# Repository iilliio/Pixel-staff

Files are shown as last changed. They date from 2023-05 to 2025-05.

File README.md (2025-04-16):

<h1>
Open Pixel Poi
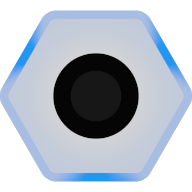
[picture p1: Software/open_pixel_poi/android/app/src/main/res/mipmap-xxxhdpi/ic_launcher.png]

</h1>

<h4>
  <a href="https://discord.gg/hErUF8A4">Store</a>
  ·
  <a href="./Firmware/MANUAL.md">User Guide</a>
  ·
  <a href="./Hardware/3D Printable Body/README.md">3D Models</a>
  ·
  <a href="./Hardware/Assembly/README.md">Assembly</a>
  ·
  <a href="./Software/README.md">Android App</a>
  ·
  <a href="https://mitchlol.github.io/#openpixelpoi">Firmware Tool</a>
  ·
  <a href="https://discord.gg/hErUF8A4">Discord</a>
</h4>

Open Pixel Poi  is an open source, 3D printable, LED pixel Poi, based around ESP32, WS2812B, and FFF/FDM manufacturing.
Designed to be simple, afforable, repairable, and customizable.
<div>
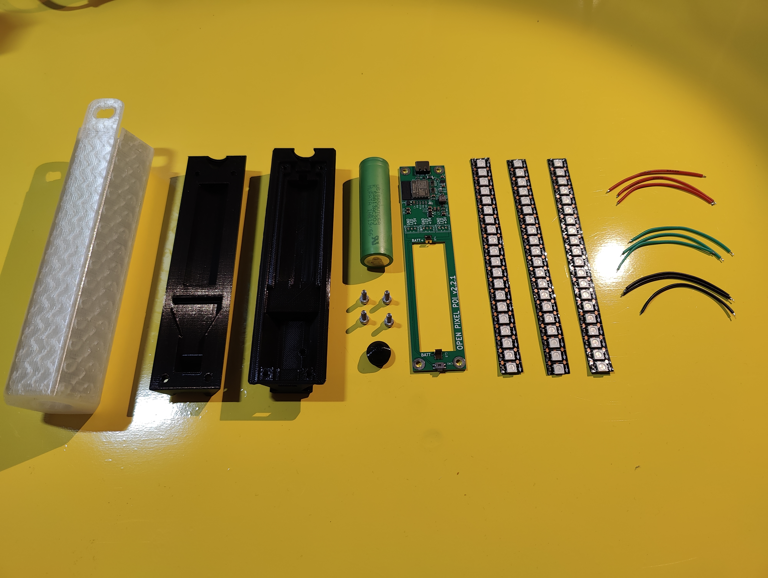
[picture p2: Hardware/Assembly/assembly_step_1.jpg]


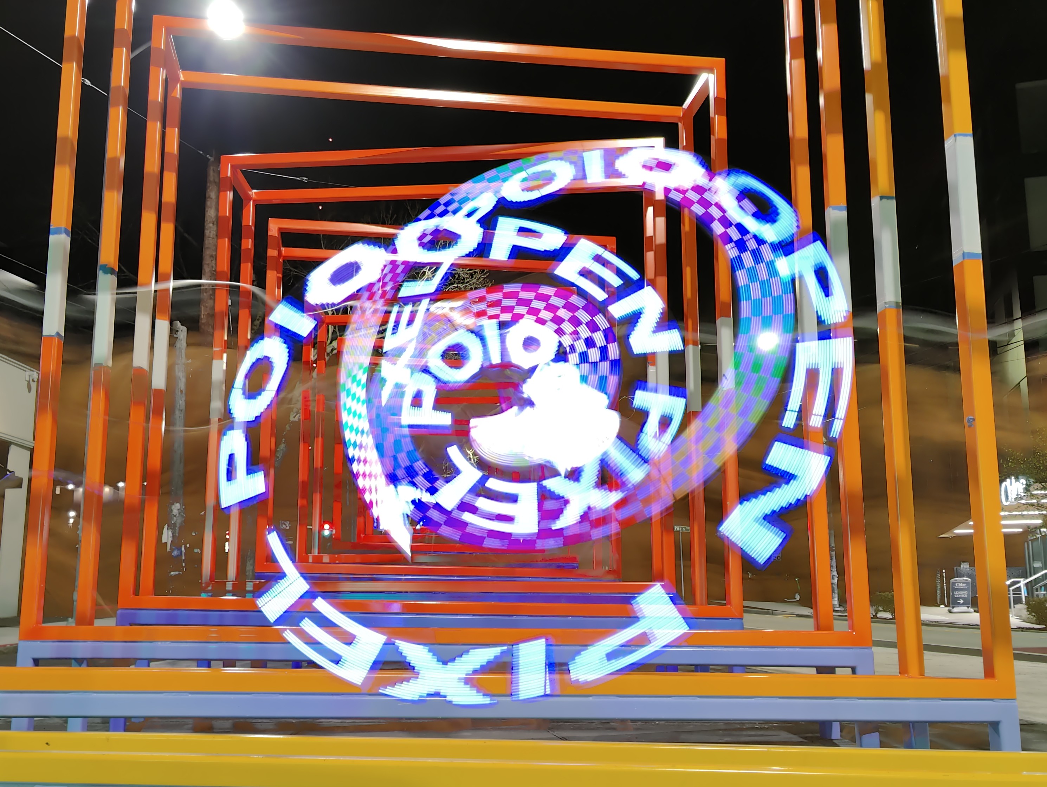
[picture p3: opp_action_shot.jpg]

</div>

#### License
[Licensed  with GPLv3](https://www.gnu.org/licenses/gpl-3.0.en.html)
Suggested donation of 5$ per set of Poi built via [paypal](https://www.paypal.com/donate/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) or purchase PCBs from store link.

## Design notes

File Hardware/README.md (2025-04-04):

# Hardware Guide

This hardware guid is split into 2 sections with more detailed instructions in each.

1. [3D Printable Body](./3D%20Printable%20Body/): Includes the files and instructions for 3D printing the main Poi body, and enclosure.
1. [Assembly](./Assembly/): Contains a detailed assembly tutorial.

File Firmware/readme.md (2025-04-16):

# Open Pixel Poi Firmware

##### Links
- [User Manual](./MANUAL.md)
- [Firmware Flashy Thing](https://mitchlol.github.io/#openpixelpoi)

##### Firmware info
This is the firmware, it is an arduino project designed to be built in arduino ide v1.8.19 on windows.
It used the adafruit neo pixel library, which must be installed through the ide.

It requires the esp32 boards to be installed, I reccomend v2.0.12 as newer versions cause led glitches.
When builiding, use the XIAO_ESP32C3 board for the gpio config to line up. All the other board settings can be default.

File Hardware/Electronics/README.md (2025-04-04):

# Kicad project
This project was designed using Kicad, and is intended for jlcpcb smt assembly. If you would like to purchase a PCB, visit the store link in the [Readme](../../README.md)

If you want to build this without a custom PCB, you can build the [old version](https://github.com/Mitchlol/Open-Pixel-Poi/tree/v2.0.0/Hardware)
Just add an undocumented pull up resistor to the button.

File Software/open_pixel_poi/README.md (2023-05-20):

# open_pixel_poi

A new Flutter project.

## Getting Started

This project is a starting point for a Flutter application.

A few resources to get you started if this is your first Flutter project:

- [Lab: Write your first Flutter app](https://docs.flutter.dev/get-started/codelab)
- [Cookbook: Useful Flutter samples](https://docs.flutter.dev/cookbook)

For help getting started with Flutter development, view the
[online documentation](https://docs.flutter.dev/), which offers tutorials,
samples, guidance on mobile development, and a full API reference.

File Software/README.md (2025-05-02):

# Open Pixel Poi Software
This is a flutter app, it is designed to run on android. No other systems have been configured yet.
<div>
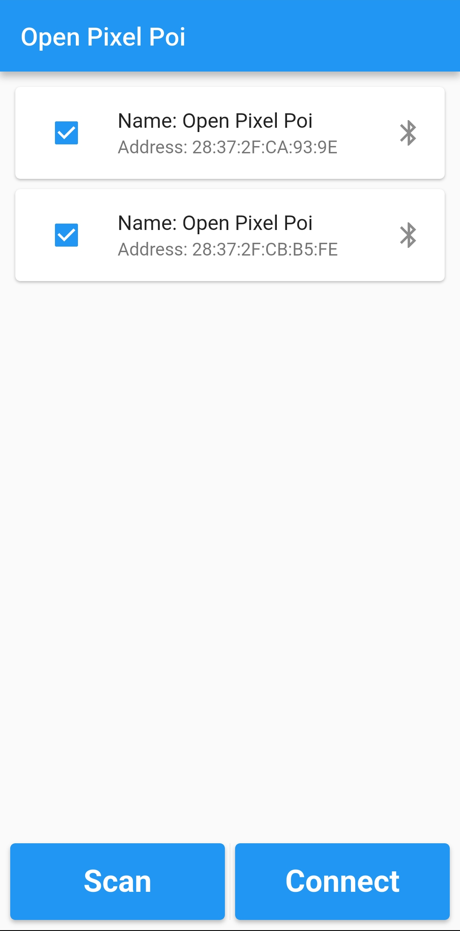
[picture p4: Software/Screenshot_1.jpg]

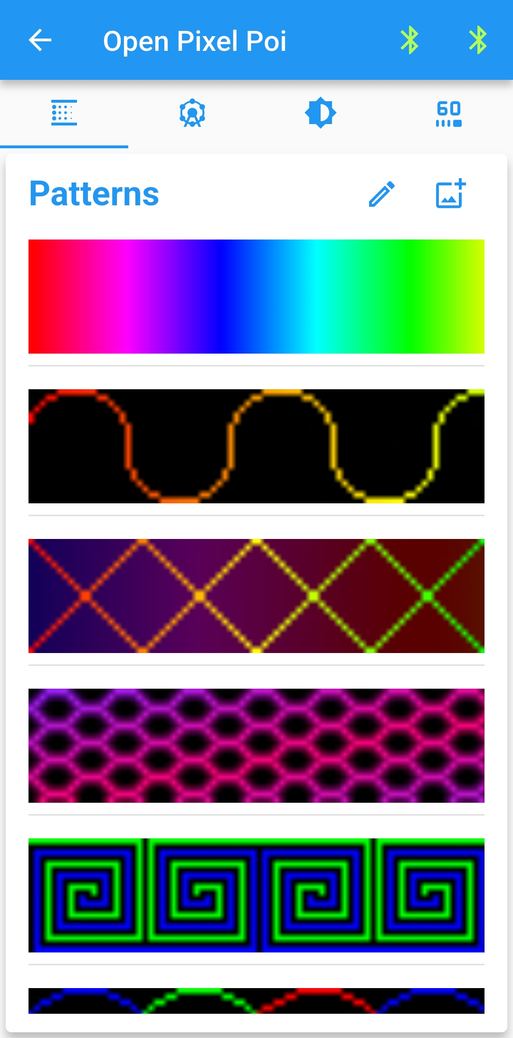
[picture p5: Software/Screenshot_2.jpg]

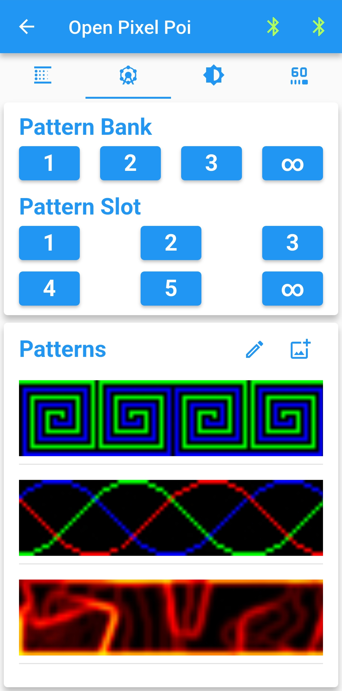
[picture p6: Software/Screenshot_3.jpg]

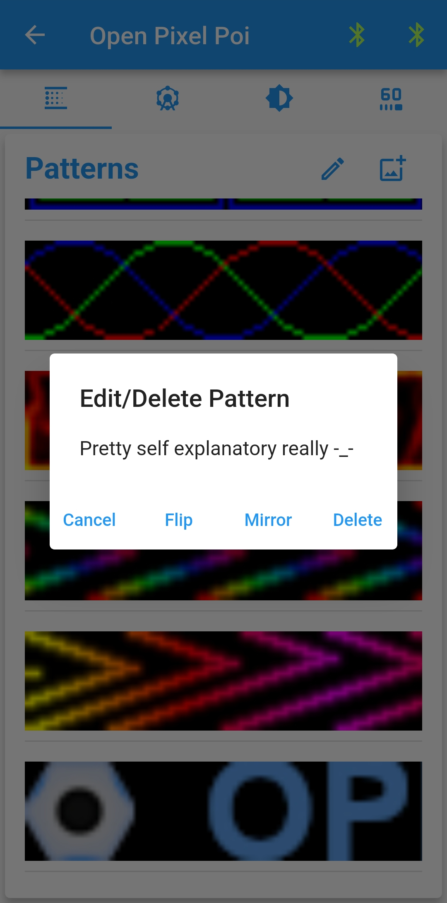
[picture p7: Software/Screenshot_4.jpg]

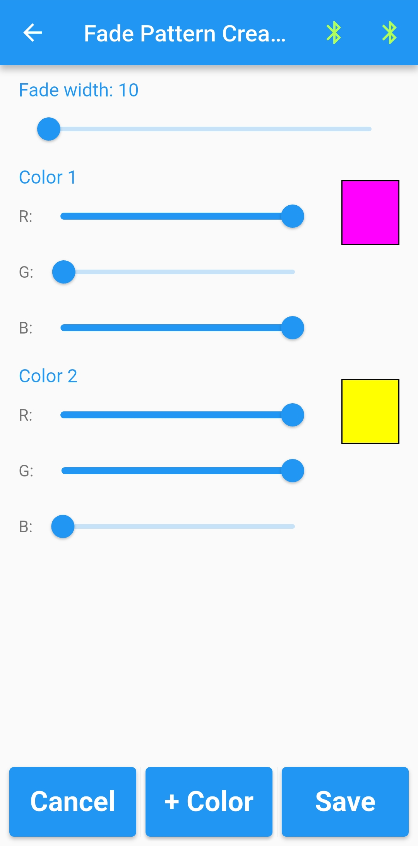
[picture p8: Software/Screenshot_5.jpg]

</div>

## Android Releases
[Open Pixel Poi v1.0.0](https://github.com/Mitchlol/Open-Pixel-Poi/raw/refs/heads/main/Software/open_pixel_poi_v1.0.0.apk)

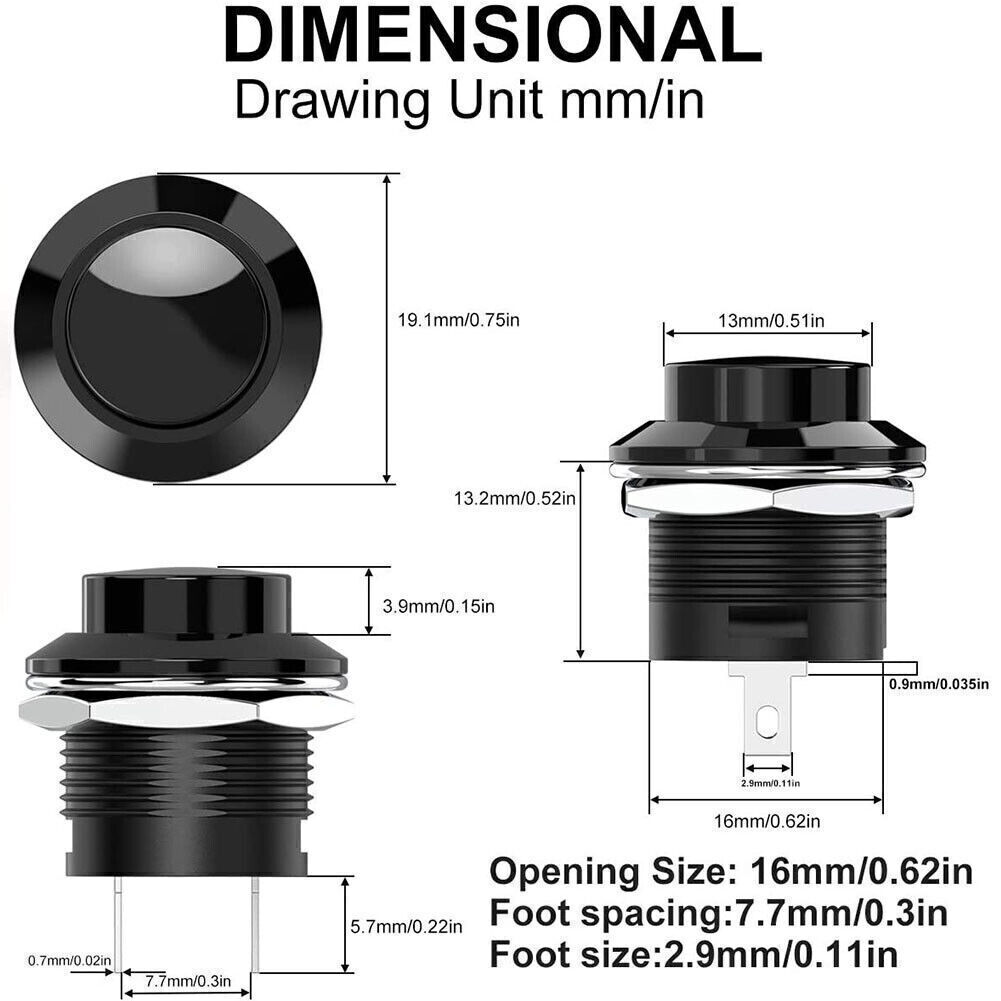
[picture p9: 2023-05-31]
Hardware/Electronics/switch2.jpg

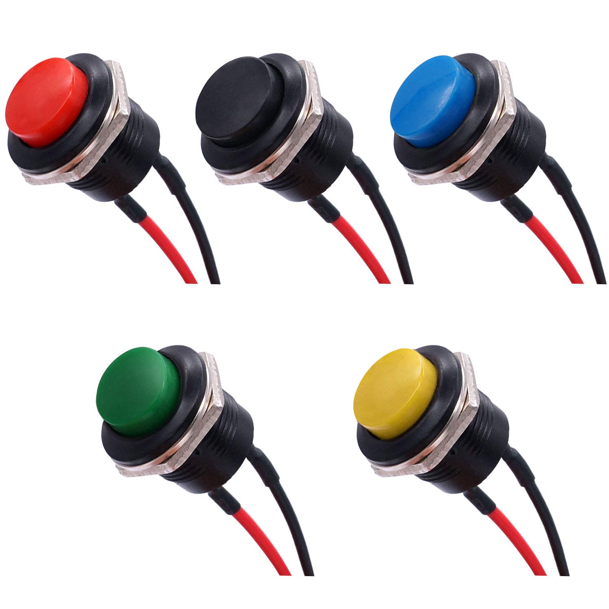
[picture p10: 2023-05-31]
Hardware/Electronics/switch.jpg

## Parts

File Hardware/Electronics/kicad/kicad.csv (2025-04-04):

Id | Designator | Footprint | Quantity | Designation | Supplier and ref
1 | C6,C7 | C_0402_1005Metric | 2 | 22u
2 | R5 | R_0603_1608Metric | 1 | 1k
3 | R4 | R_0603_1608Metric | 1 | 10k
4 | C1 | C_0805_2012Metric | 1 | 100n
5 | U3 | ESP32-C3-MINI-1_EXP | 1 | ESP32-C3-MINI-1-N4
6 | SW2,SW1 | SW_SPST_B3U-1000P | 2 | SW_Push
7 | J1 | JST_PH_B3B-PH-K_1x03_P2.00mm_Vertical | 1 | Conn_01x03_Socket
8 | R2,R1 | R_0603_1608Metric | 2 | 5k1
9 | U5 | SOT-223-3_TabPin2 | 1 | TLV1117-33
10 | F1 | Fuse_1206_3216Metric | 1 | Polyfuse_Small (1A)
11 | U1 | SOT-666 | 1 | USBLC6-2P6
12 | D1 | LED_0603_1608Metric | 1 | LED
13 | SW3 | Panasonic_EVQPUL_EVQPUC | 1 | SW_Push
14 | R3 | R_0603_1608Metric | 1 | 100k
15 | J6 | USB_C_Receptacle_HRO_TYPE-C-31-M-12 | 1 | USB_C_Receptacle_USB2.0_16P
16 | Q1 | SOT-23 | 1 | BSS138

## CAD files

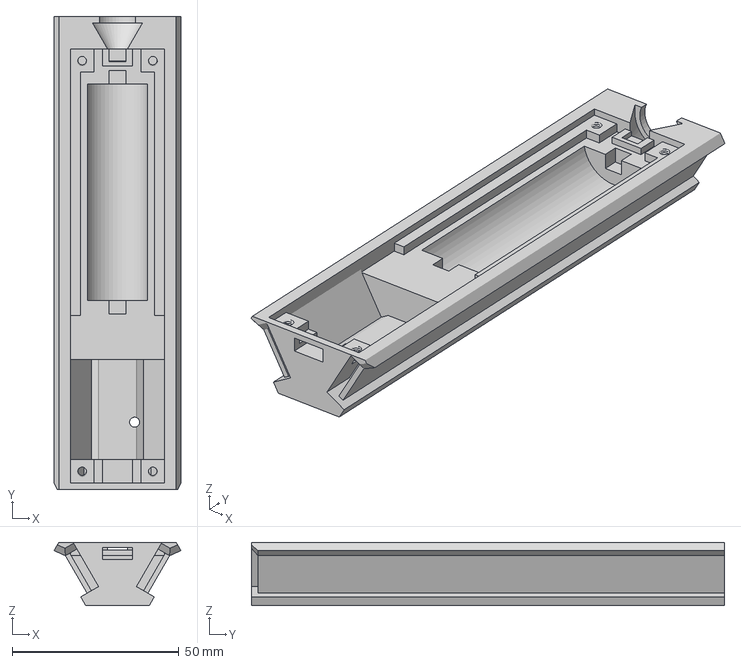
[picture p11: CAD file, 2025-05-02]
Hardware/3D Printable Body/Open Pixel Poi - Body - Top.3mf
38.1 x 142.0 x 19.0 mm

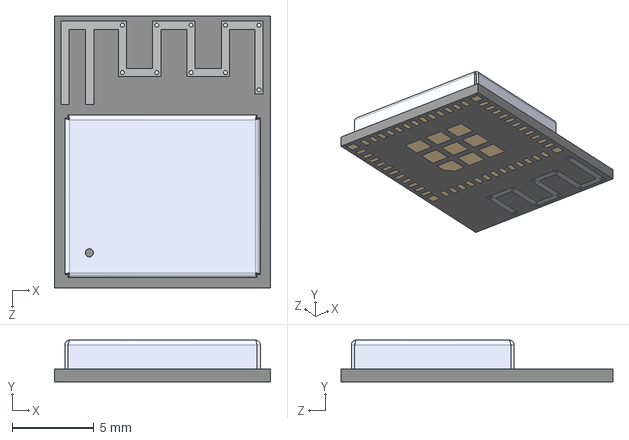
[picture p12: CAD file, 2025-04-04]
Hardware/Electronics/kicad/ESP32_C3_MINI_1_N4 (v2)/ESP32-C3-MINI-1-N4.step
13.2 x 2.55 x 16.6 mm

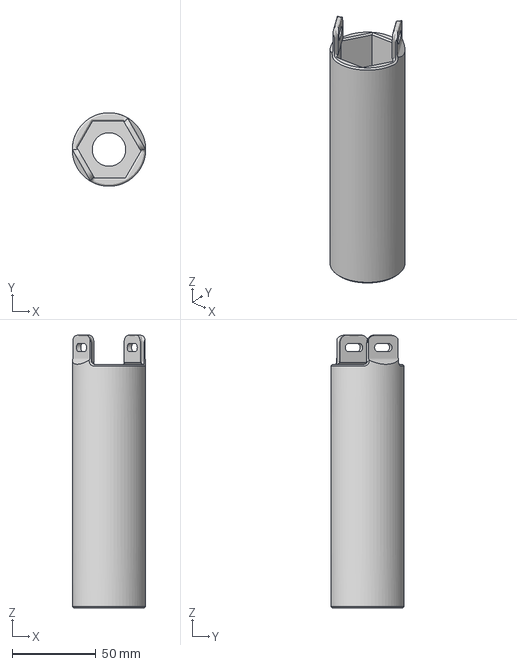
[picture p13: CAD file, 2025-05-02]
Hardware/3D Printable Body/Open Pixel Poi - Shell - Round Diffused.3mf
43.9 x 43.9 x 163.0 mm

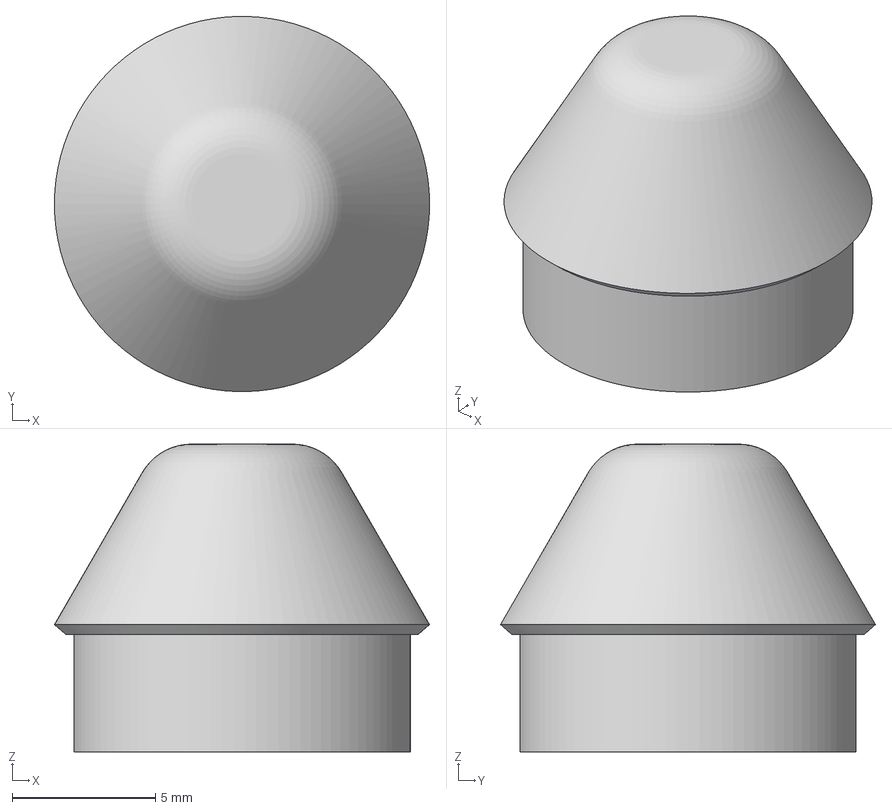
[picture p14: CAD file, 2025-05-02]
Hardware/3D Printable Body/Open Pixel Poi - Body - Button.3mf
13.1 x 13.1 x 10.8 mm

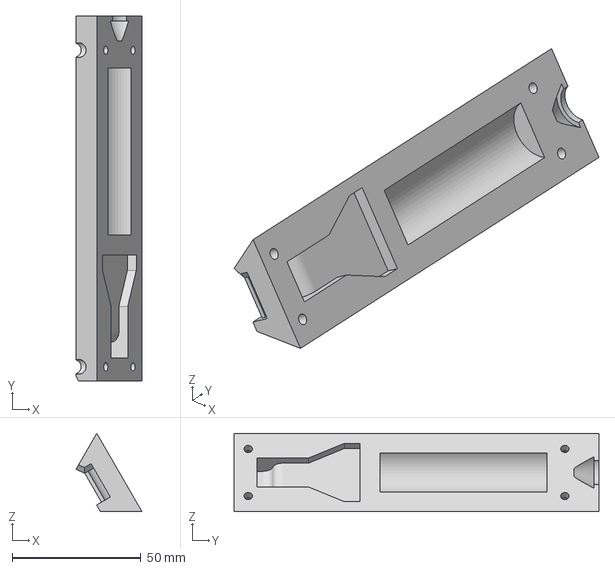
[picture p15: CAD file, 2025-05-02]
Hardware/3D Printable Body/Open Pixel Poi - Body - Bottom.3mf
25.7 x 142.0 x 30.5 mm

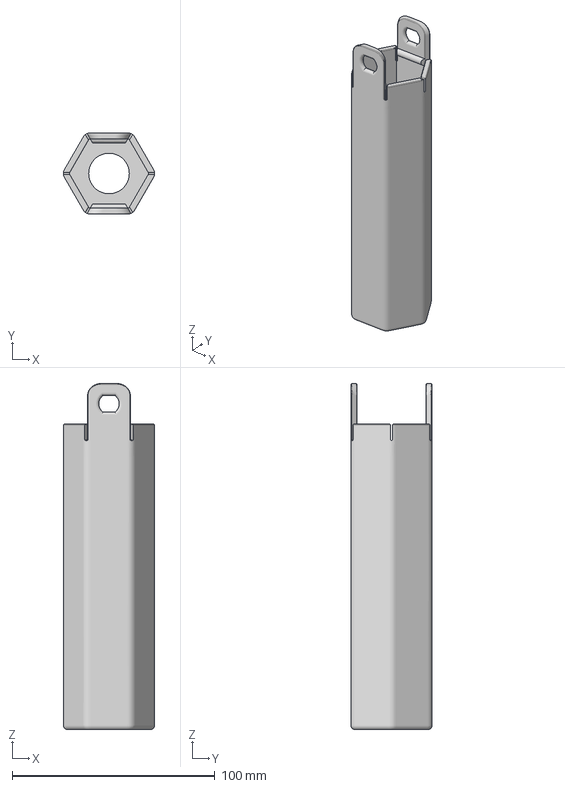
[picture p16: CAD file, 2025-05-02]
Hardware/3D Printable Body/Open Pixel Poi - Shell - Hex.3mf
45.0 x 40.0 x 170.5 mm

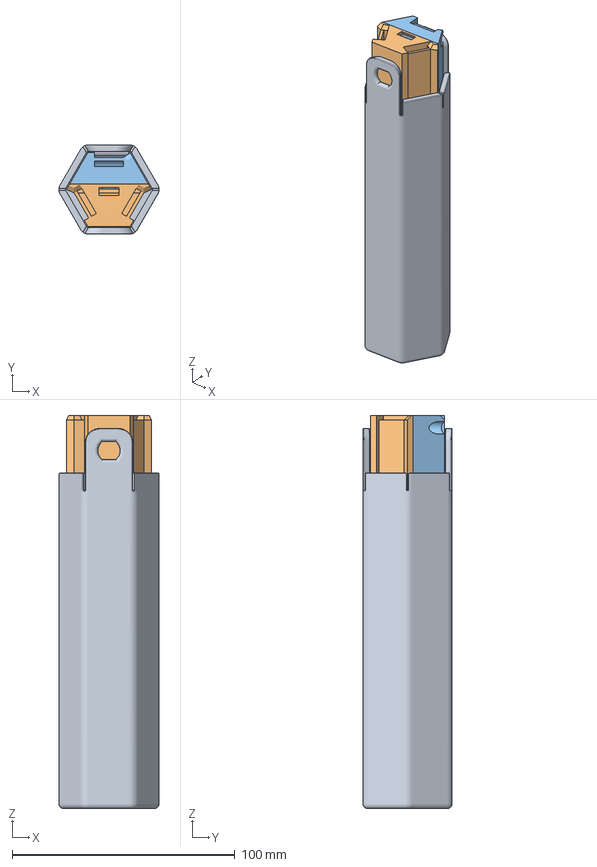
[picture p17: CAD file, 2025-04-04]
Hardware/3D Printable Body/Open Pixel Poi - All Parts In One File.3mf
45.0 x 40.0 x 176.2 mm

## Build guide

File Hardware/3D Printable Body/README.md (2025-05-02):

# Open Pixel Poi - 3D Printed Body

## Main Body
Print all the main body parts in **PLA** or any other rigid material. Slicer profiles such as layer height an infill are not important, just make sure you can do the overhangs. The individual body files have been pre-oriented so that no supports/brims/rafts/etc are required, see the section on orientation below to confirm your orientation. You need 1 of each part per poi, or 2 of each for a pair.
###### Main body parts are:
1. [Open Pixel Poi - Body - Top](<https://github.com/Mitchlol/Open-Pixel-Poi/raw/refs/heads/main/Hardware/3D%20Printable%20Body/Open%20Pixel%20Poi%20-%20Body%20-%20Top.3mf>)
1. [Open Pixel Poi - Body - Bottom](<https://github.com/Mitchlol/Open-Pixel-Poi/raw/refs/heads/main/Hardware/3D%20Printable%20Body/Open%20Pixel%20Poi%20-%20Body%20-%20Bottom.3mf>)
1. [Open Pixel Poi - Body - Button](<https://github.com/Mitchlol/Open-Pixel-Poi/raw/refs/heads/main/Hardware/3D%20Printable%20Body/Open%20Pixel%20Poi%20-%20Body%20-%20Button.3mf>)

## Outer Shell
The outer shell must be printed in **Clear / Transparent TPU**. Ive included 2 shell variants. For the original hex shell, I like how it looks with 10% gyroid infill. The round shell should be mostly unaffected by infill, as it has thin walls and internal cavities to control diffusion. Both files are preoriented and do not require any supports/brims/rafts/etc, see the section on orientation below to confirm your orientation. You need 1 shell per poi, so that means 2 shells for a pair. If you're undecided which shell you want, go with the round one.
###### main body parts are:
1. **Option 1:** [Open Pixel Poi - Shell - Hex](<https://github.com/Mitchlol/Open-Pixel-Poi/raw/refs/heads/main/Hardware/3D%20Printable%20Body/Open%20Pixel%20Poi%20-%20Shell%20-%20Hex.3mf>)
1. **Option 2:** [Open Pixel Poi - Shell - Round Diffused](<https://github.com/Mitchlol/Open-Pixel-Poi/raw/refs/heads/main/Hardware/3D%20Printable%20Body/Open%20Pixel%20Poi%20-%20Shell%20-%20Round%20Diffused.3mf>)

## Orientation
The parts all print without supports when oriented like this. Take special note of orientation the bottom half of the body, the led groove is an overhang rather than requiring supports.
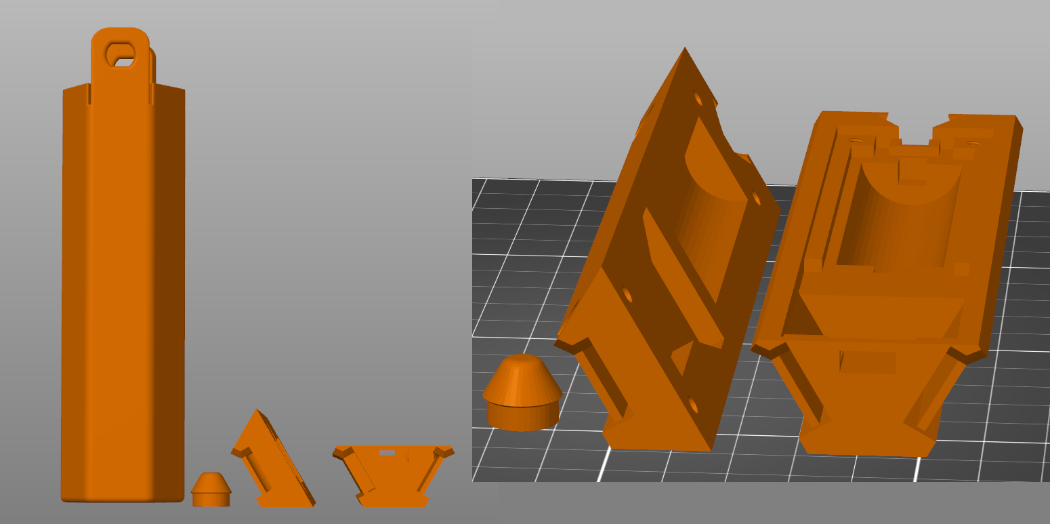
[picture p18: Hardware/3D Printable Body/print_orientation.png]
orientation


## All in one file
Alternatively [Open Pixel Poi - All Parts In One File](<Open Pixel Poi - All Parts In One File.3mf>) contains all the parts of a single poi body. You will need to split the object to seperate out the parts, and orient them on your own.

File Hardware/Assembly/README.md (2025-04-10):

# Open Pixel Poi Assembly Guide

## intro

This is basic assembly guide, and while assembly should be intuitive, this guide includes a few tips, tricks, and order of operations optimizations. It does not include any soldering specific info, as that is out of scope.

For a realtime assembly video with soldering click [here](https://youtu.be/lT4Q7nI5Dq8?si=qJWZAIUzumP1a3XG)

## Step 1: 
###### Gather your parts
For a single poi you will need:
1. 3D Printed outer shell (clear TPU) - 1x
1. 3D Printed body top (PLA) - 1x
1. 3D Printed body bottom (PLA) - 1x
1. 3D Printed button (PLA) - 1x
1. M3 x 8mm Hex Socket Head Cap Screw - 4x
1. 18650 Li-Ion battery - 1x
1. Open Pixel Poi PCB - 1x
1. WS2812b 144/m adhesive back stip 20 leds long (no waterproofing) - 3x
1. 26 AWG Silicone Stranded wire 2.75" long - 9x (3 colors, 3 of each)

wiring

## Step 2
###### Solder wires to the LED strips
While any color will work, using the right color keeps things neat!
Black = ground
Red = power
Any other color =  data
wiring

## Step 3
###### Solder 2 LED strips to the top of the board
One strip to each of the 2 outer connection points.
You can thread the wires thorugh the holes if you like, but if you don't,
make sure they go away from the battery and towards the USB port.

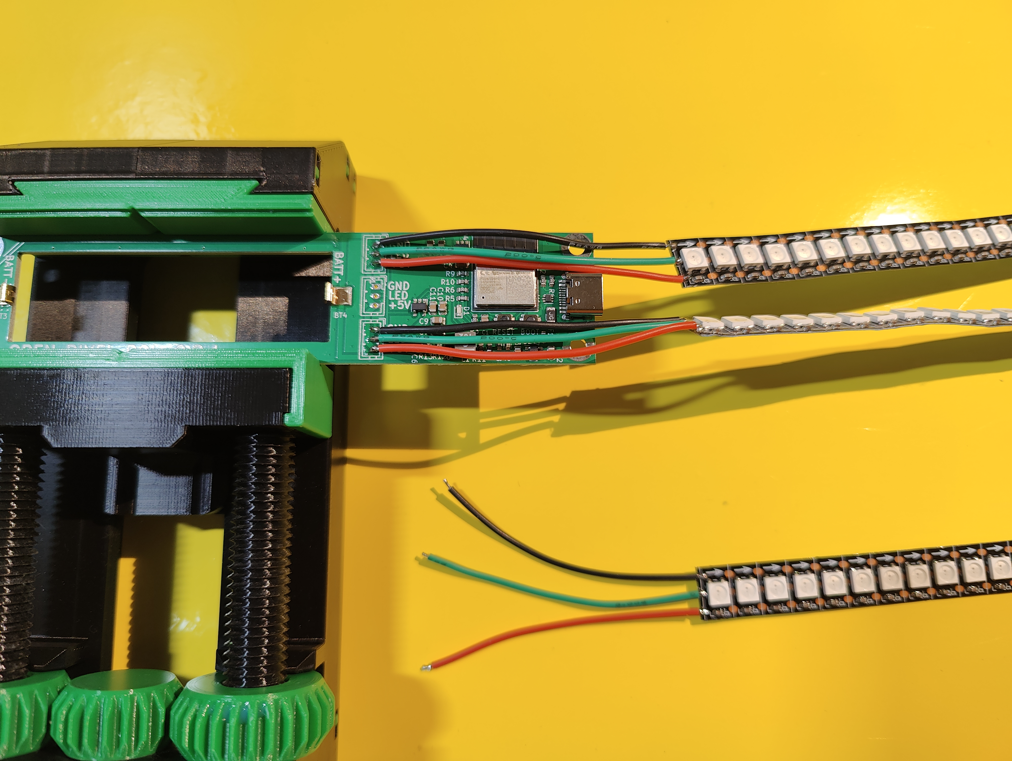
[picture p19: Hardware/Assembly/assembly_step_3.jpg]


## Step 4
###### Solder the 3rd LED strip to the bottom of the middle connection
Same as step 3, just using the middle connection on the bottom side of the board.
wiring

## Step 5
###### Thread 2 LED strips through the top part of the poi body
The top body part is the one with holes for 2 led strips!
You need to bend them a little to get it through, but you can do it!
Take note that they aren't crossed, and that they are twisted the right way to point outward when folded down.
You can twist the wiring later if you get it wrong, but it is a pain.
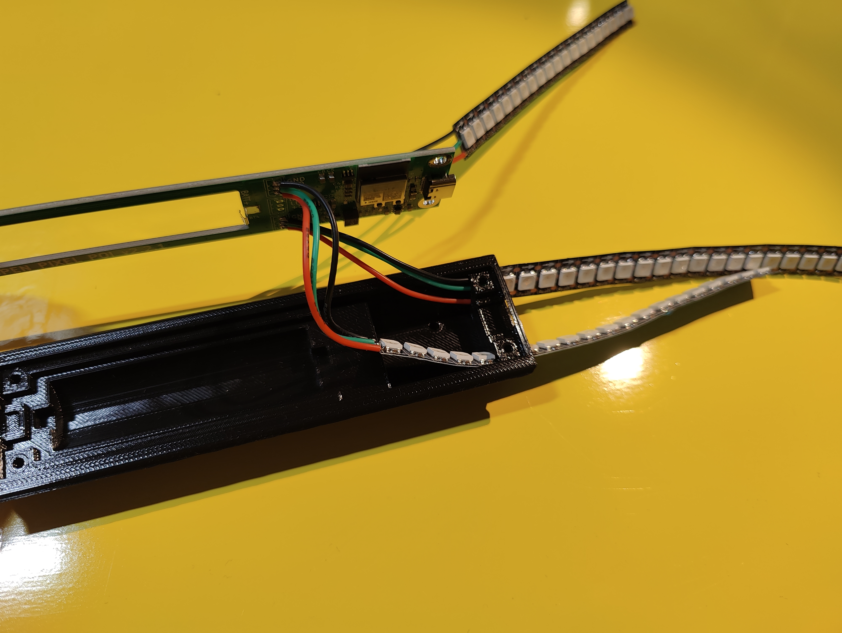
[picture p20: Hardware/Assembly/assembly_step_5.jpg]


## Step 6
###### Insert the battery into the top of the body
Push the battery into the body, making sure the positive end is towards the USB port, and lines up with the batt+ label on the board.
It is a tight fit, this is intentional.
It goes in easiest if you slide it in all at once, rather than one end first.
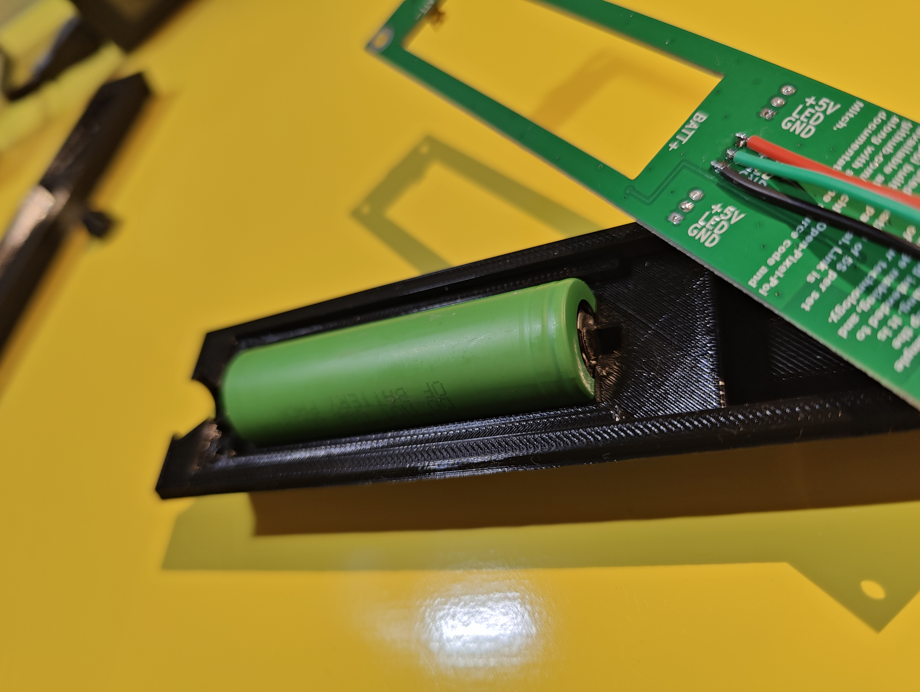
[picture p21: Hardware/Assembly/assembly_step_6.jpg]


## Step 7
###### Slot in the PCB
Order is important here.
First slide the usb port into the usb port hole at the top of the poi, while keeping the switch end of the board elevated.
Then, carefully lever down the board over the battery, this will turn the poi on.
Finally, make sure the bottom (and sides) of the pcb are fully seated and flush with the body.
This is often tight as well and may snap in.
You can turn the poi off with the switch see the [user manual]()
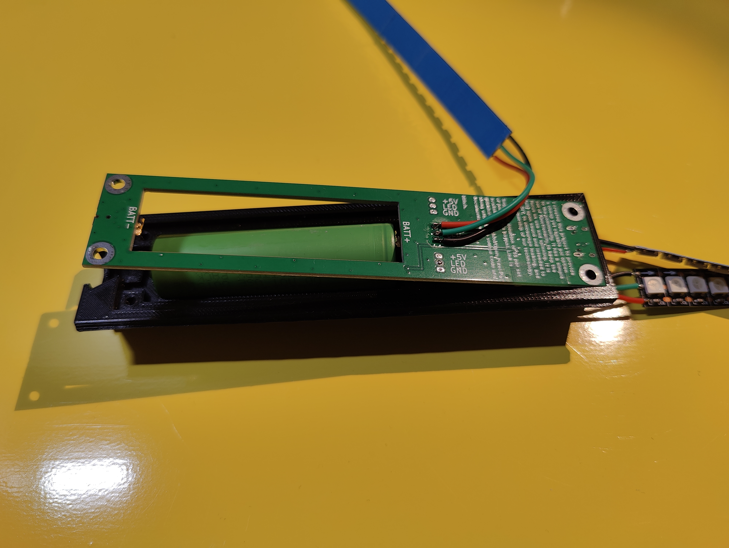
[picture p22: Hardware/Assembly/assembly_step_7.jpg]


## Step 8
###### Snap the button into body
Push the button into the body, it is a snap fit.
**Take extra care to avoid contact with the switch on bottom of the board!**
**It can break easy.**
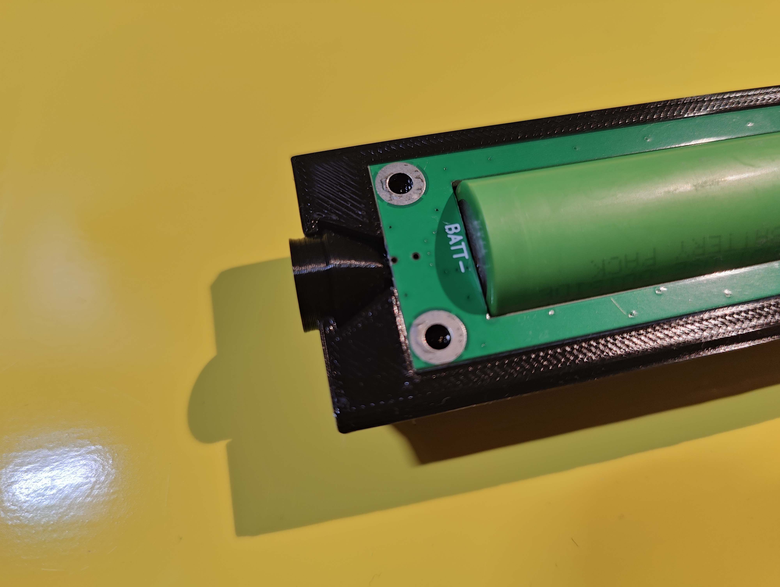
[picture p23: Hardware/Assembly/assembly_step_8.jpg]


## Step 9
###### Thread the 3rd led strip through the bottom of the body
Same as the first 2, but easier, make sure it is twisted the right way.
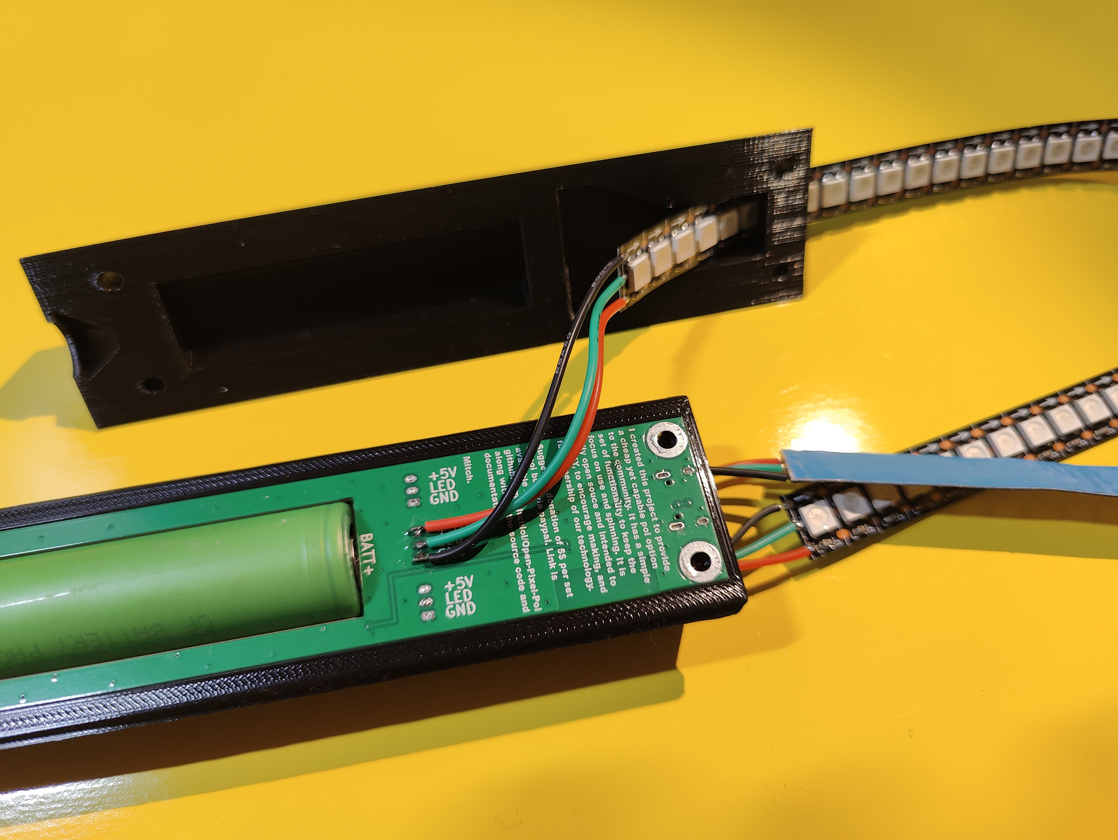
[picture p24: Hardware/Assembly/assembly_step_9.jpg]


## Step 10
###### Push the 2 body halves together
Once again, the battery is snug. Make sure no wires get pinched.
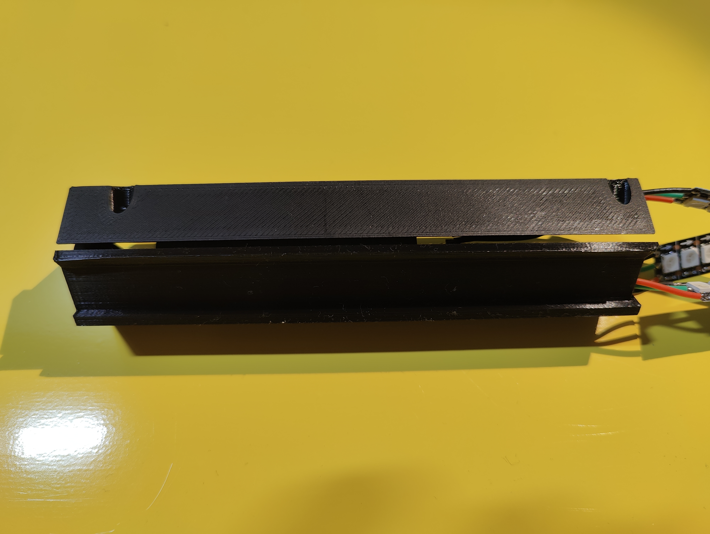
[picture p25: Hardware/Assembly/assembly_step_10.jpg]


## Step 11
###### Screw the two halves together
These screws are going directly into a 3d print, so be gentle, you don't want to strip the threads. You can hold it up to the light to make sure there is no visible gap between the 2 halfs, to know it is snug.

Alternativley, you can just wrap the sucker in packing tape, just make sure you do it after sticking on the LEDs.
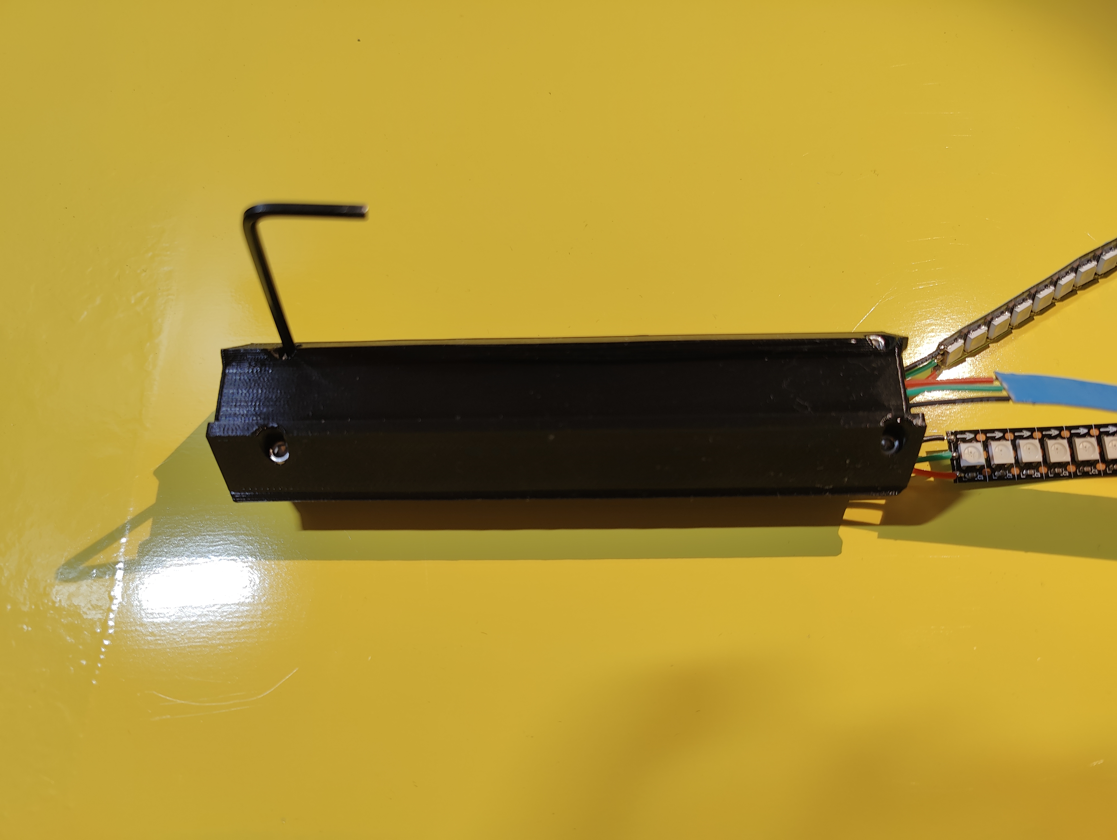
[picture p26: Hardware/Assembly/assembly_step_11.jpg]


## Step 12
###### Apply the LED strips
Peel the backing off the LED strips, and apply to the to body. 
One for each recess. 
Start from the bottom of the poi and work back towards the wiring. 
If you cut the bottom of the strip flush with the bottom LED, it should line up perfectly.
Do this for all 3 strips.
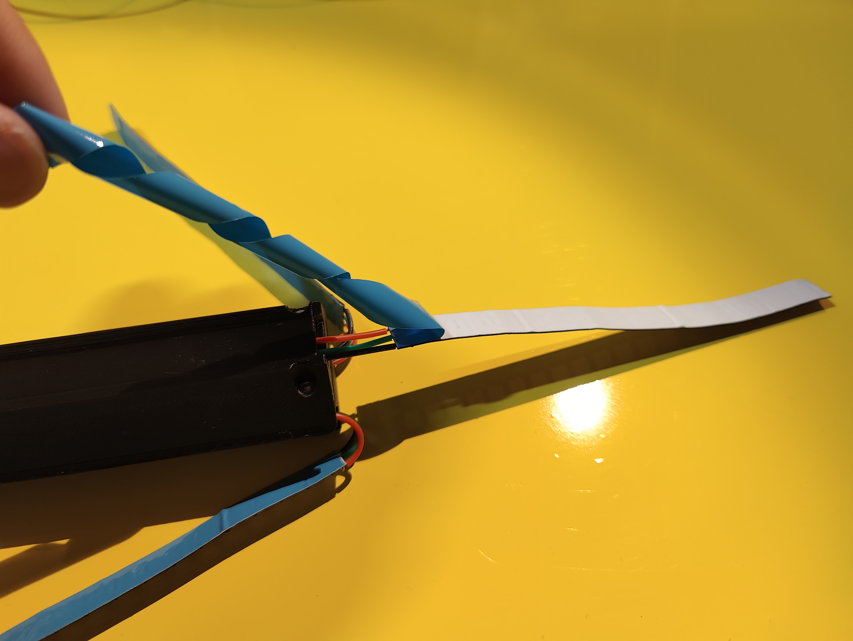
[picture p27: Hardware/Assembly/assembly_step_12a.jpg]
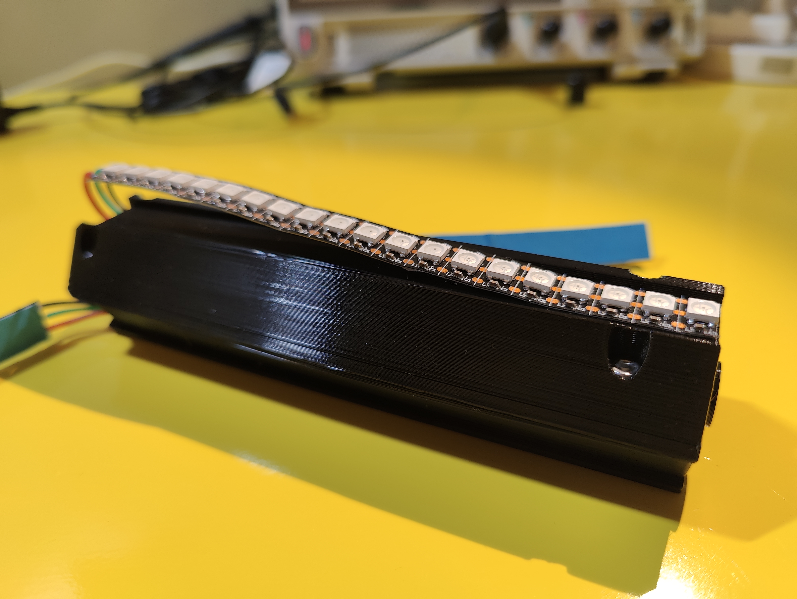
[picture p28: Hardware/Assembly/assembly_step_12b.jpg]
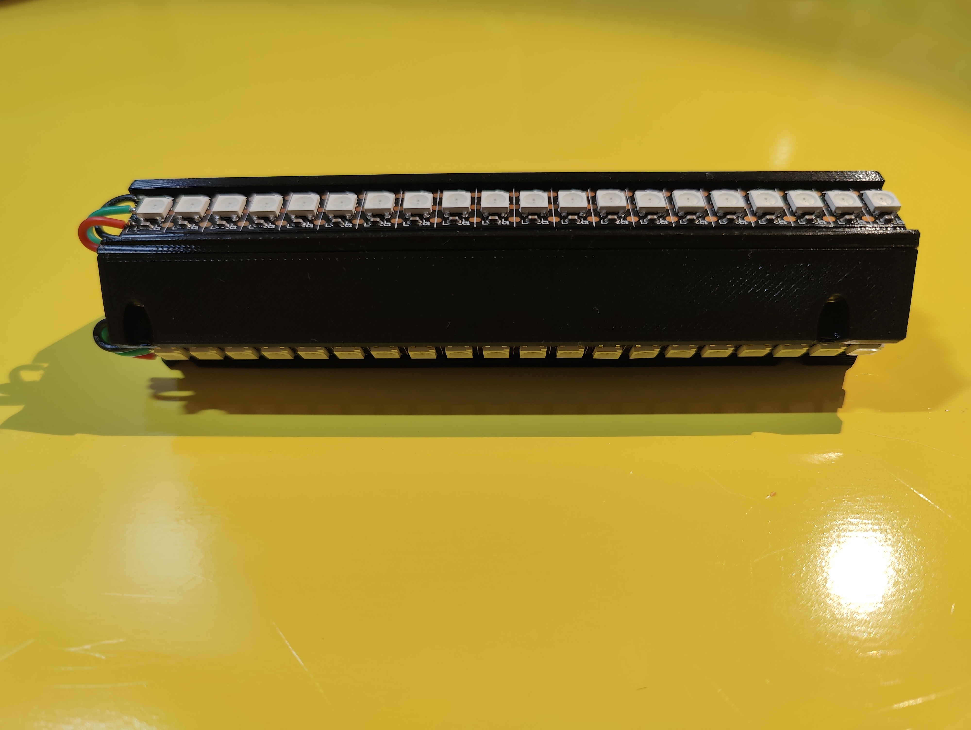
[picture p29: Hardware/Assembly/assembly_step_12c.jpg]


## Step 13
###### Tuck excess wireing into the body
Using blunt tweezers makes light work of this.
I tuck the 2 top strips away from the exposed screws.
I don't think they can move enough to wear thorugh and cause a short. But you can add a dab of hot glue to ease your mind if you wish.
wiring

## Step 14
###### Slot the body into the shell
Pull the two longer tabs apart to get the clearnace needed.
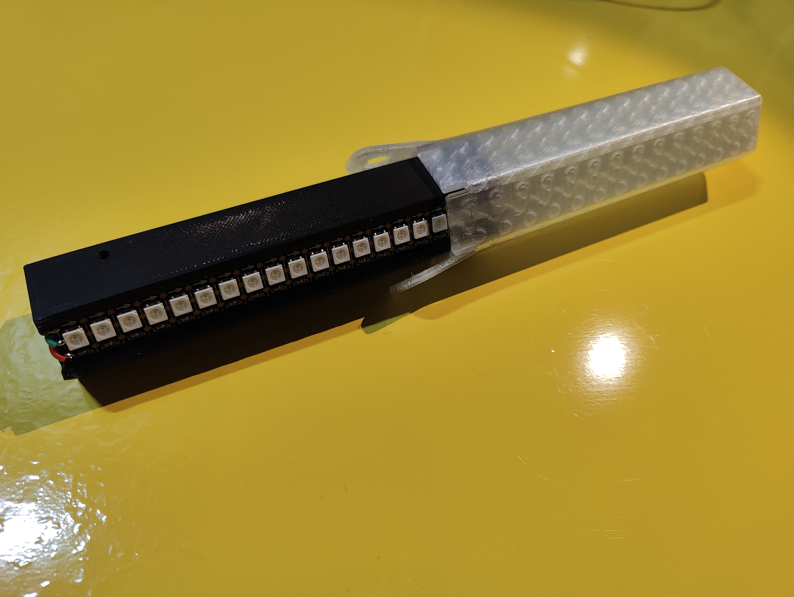
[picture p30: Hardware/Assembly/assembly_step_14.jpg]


## Step 15
###### Party!
Woah! Where did that 2nd poi come from?
wiring

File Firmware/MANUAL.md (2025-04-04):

# Open Pixel Poi User Manual

## Quirks & Features
Open pixel poi have a single button menu which gives access to

1. Power on/off
1. 15 pattern slots (split into 3 pattern banks)
1. 5 Brightness levels
1. 10 speeds
1. Auto patten cycle mode
1. Voltage display

Note: a freshly flashed firmware will have no pattens and display
a yellow strobe for all 5 of the pattern slots, untill they are 
filled via the app.

Also Note: The lowest brightness level can only display primary 
colors, this means patterns and color based battery level will 
have very low fidelity. Because the LEDs are powered on at the 
lowest possible level, it is not possible for it to do partial 
brightness to blend colors. The second to lowest level can also
struggle a little.

## Power On/Off
When off, a single button press will turn the poi on.
When on, a single press and hold will turn the poi off.

Note: When turning the poi off, the press andhold will initially
show the blue dot animation, followed by a green/yellow/red battery
level indicator, and finally a blinking red fade out, which is
the shut down animation. You can release the button once the red
blinking animation starts.

## Changing Patterns
A single button press will show the blue dot animation, and then
change to the next pattern. After the 5th pattern, the poi will
loop back to the first pattern.

## Auto pattern cycling
a double press which will show the magenta dot 
animation and begin automatically cycling through all 5 patterns.

## Changing pattern banks
A single press, followed by a press and hold will show the pink
dot pattern cycling animation, and then ramp up through the pattern
bank slots. There are 3 slots, which hold 5 patterns each. Release
the hold at the desired bank to select it. Keep holding past the
3rd bank and release when the poi display full magenta to auto
cycle all patterns in all banks

## Changing Brightness
A double press, followed by a press and hold will show the white
dot animation, and then ramp up through the brightness levels.
Release the hold at the desired brightness level to select it.

## Changing Speed
A tripple press, followed by a press and hold will show the red
dot animation, and then ramp up through the speed levels.
Release the hold at the desired speed level to select it.

## Battery level monitoring
A single press and hold will show the battery level as a color.
Green is full, red is empty, shades of yellow inbetween.
If you hold too long, it will go into the shutdown sequence.

Pressing the button 4 times which will show the green->red dot 
animation and enter the voltage display mode. In this mode the 
blue leds represent the integer value of the cell voltage, and
remanining leds represent the tenths of a volt fraction. The 
remaining leds are group into 3s for easier counting, and the
color varies from green to red based on the battery level.

## Low battery
When the battery level gets low (below 3.45v) the brightness will
be limited to level 3 max.

When the battery level gets critical (below 3.33v) the poi will
only display 2 red pixels at either end, at the miniumum level.

When the battery level gets even lower (3.25v) the poi will
automatically shut down.

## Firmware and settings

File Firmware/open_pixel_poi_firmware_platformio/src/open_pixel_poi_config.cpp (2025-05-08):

#ifndef _OPEN_PIXEL_POI_CONFIG
#define _OPEN_PIXEL_POI_CONFIG

#include <FS.h>
#include <SPIFFS.h>
#include <Preferences.h>

#define DEBUG  // Comment this line out to remove printf statements in released version
#ifdef DEBUG
#define debugf(...) Serial.print("  <<config>> ");Serial.printf(__VA_ARGS__);
#define debugf_noprefix(...) Serial.printf(__VA_ARGS__);
#else
#define debugf(...)
#define debugf_noprefix(...)
#endif

enum DisplayState {
  DS_PATTERN,
  DS_PATTERN_ALL,
  DS_PATTERN_ALL_ALL,
  DS_WAITING,
  DS_WAITING2,
  DS_WAITING3,
  DS_WAITING4,
  DS_WAITING5,
  DS_VOLTAGE,
  DS_VOLTAGE2,
  DS_BANK,
  DS_BRIGHTNESS,
  DS_SPEED,
  DS_SHUTDOWN
};

#define BATTERY_LATCH 0.05
#define BATTERY_VOLTAGE_LOW 3.45
#define BATTERY_VOLTAGE_CRITICAL 3.33
#define BATTERY_VOLTAGE_SHUTDOWN 3.25

#define PATTERN_BANK_SIZE 5
#define PATTERN_BANK_COUNT 3 

// Default number of LEDs if not configured
#define DEFAULT_NUMBER_OF_LEDS 80
// Maximum number of frames to store
#define MAX_FRAMES 400
// Calculate pattern buffer size: 3 bytes (RGB) * number of LEDs * max frames
#define PATTERN_BUFFER_SIZE (3 * DEFAULT_NUMBER_OF_LEDS * MAX_FRAMES)

enum BatteryState {
  BAT_OK,
  BAT_LOW,
  BAT_CRITICAL,
  BAT_SHUTDOWN,
};
  
class OpenPixelPoiConfig {
  private:
    Preferences preferences;
    
  public:
    // Runtime State
    float batteryVoltage = BATTERY_VOLTAGE_LOW;
    BatteryState batteryState = BAT_OK;
    DisplayState displayState = DS_PATTERN;
    long displayStateLastUpdated = 0;
    // Settings (come in from the app)
    uint8_t ledBrightness; 
    uint8_t animationSpeed;
    uint8_t patternSlot;
    uint8_t patternBank;
    uint8_t numberOfLeds = DEFAULT_NUMBER_OF_LEDS;
    // Pattern
    uint8_t frameHeight; 
    uint16_t frameCount;
    uint8_t *pattern = (uint8_t *) malloc(PATTERN_BUFFER_SIZE);
    uint16_t patternLength;

    // Variables
    long configLastUpdated;

    void setLedBrightness(uint8_t ledBrightness) {
      debugf("Save Brightness = %d\n", ledBrightness);
      this->ledBrightness = ledBrightness;
      preferences.putChar("brightness", this->ledBrightness);
      this->configLastUpdated = millis();
    }
    
    void setAnimationSpeed(uint8_t animationSpeed) {
      debugf("Save Speed = %d\n", animationSpeed * 2);
      this->animationSpeed = animationSpeed;
      preferences.putChar("animationSpeed", this->animationSpeed);
      this->configLastUpdated = millis();
    }

    void setPatternSlot(uint8_t patternSlot, bool save) {
      debugf("Save Pattern Slot = %d\n", patternSlot);
      this->patternSlot = patternSlot;
      if(save){
        preferences.putChar("patternSlot", this->patternSlot);
      }

      loadFrameHeight();
      loadFrameCount();
      fillDefaultPattern();
      loadPattern();

      debugf("- frame\n");
      debugf("  - height = %d\n", this->frameHeight);
      debugf("  - count = %d\n", this->frameCount);
      
      this->configLastUpdated = millis();
    }

    void setPatternBank(uint8_t patternBank, bool save) {
      this->patternBank = patternBank;
      if(save){
        preferences.putChar("patternBank", this->patternBank);
      }
      loadFrameHeight();
      loadFrameCount();
      fillDefaultPattern();
      loadPattern();
      
      this->configLastUpdated = millis();
    }
    
    void setFrameHeight(uint8_t frameHeight) {
      this->frameHeight = frameHeight;
      String key = "p";
      key += this->patternSlot + (this->patternBank * PATTERN_BANK_SIZE);
      key += "Height";
      preferences.putChar(key.c_str(), this->frameHeight);
      this->configLastUpdated = millis();
    }
    
    void setFrameCount(uint16_t frameCount) {
      this->frameCount = frameCount;
      String key = "p";
      key += this->patternSlot + (this->patternBank * PATTERN_BANK_SIZE);
      key += "FCount";
      preferences.putUShort(key.c_str(), this->frameCount);
      this->configLastUpdated = millis();
    }
    
    void savePattern() {
      debugf("Save Pattern\n");
      debugf("- length = %d", this->patternLength);
      for (int i=0; i<this->patternLength; i+=3) {
        if (i%this->frameHeight*3 == 0) {
          debugf_noprefix("\n");
          debugf("  ");
        }
        debugf_noprefix("0x%02X%02X%02X ", this->pattern[i], this->pattern[i+1], this->pattern[i+2]);
      }
      debugf_noprefix("\n");

      File file = SPIFFS.open(String("/pattern") + (this->patternSlot + (this->patternBank * PATTERN_BANK_SIZE)) + ".oppp", FILE_WRITE);
      if(!file || file.isDirectory()){
        debugf("− failed to open file for reading\n");
      }else{
        debugf(" - opened file for writing: %d\n");
        
        int written = file.write(pattern, patternLength);
        file.close();
        debugf(" - this much written: %d\n", written);
      }
      
      this->configLastUpdated = millis();
    }

    void fillDefaultPattern(){
      for (int i=0; i < this->frameCount; i++) {
        for (int j=0; j < this->frameHeight; j++) {
          if(i % 2 == 1){
            pattern[(i * this->frameHeight * 3) + (j*3) + 0] = 0xFF;
            pattern[(i * this->frameHeight * 3) + (j*3) + 1] = 0xFF;
            pattern[(i * this->frameHeight * 3) + (j*3) + 2] = 0x00;
          }else{
            pattern[(i * this->frameHeight * 3) + (j*3) + 0] = 0x00;
            pattern[(i * this->frameHeight * 3) + (j*3) + 1] = 0x00;
            pattern[(i * this->frameHeight * 3) + (j*3) + 2] = 0x00;
          }
        }
      }
    }

    void loadPattern(){
      File file = SPIFFS.open(String("/pattern") + (this->patternSlot  + (this->patternBank * PATTERN_BANK_SIZE)) + ".oppp");
      if(!file || file.isDirectory()){
        debugf("− failed to open file for reading\n");
      }else{
        debugf(" - this much available: %d\n", file.available());
        file.read(pattern, file.available());
        file.close();
      }
    }

    void loadFrameHeight(){
      String key = "p";
      key += (this->patternSlot  + (this->patternBank * PATTERN_BANK_SIZE));
      key += "Height";
      this->frameHeight = preferences.getChar(key.c_str(), this->numberOfLeds);
    }

    void loadFrameCount(){
      String key = "p";
      key += (this->patternSlot  + (this->patternBank * PATTERN_BANK_SIZE));
      key += "FCount";
      debugf("key = %s\n", key);
      this->frameCount = preferences.getUShort(key.c_str(), 2);
    }

    void setNumberOfLeds(uint8_t numberOfLeds) {
      debugf("Save Number of LEDs = %d\n", numberOfLeds);
      this->numberOfLeds = numberOfLeds;
      preferences.putChar("numberOfLeds", this->numberOfLeds);
      this->configLastUpdated = millis();
    }
      
    
    void setup() {
      debugf("Setup begin\n");
      debugf("Load Config (setup)\n");

      if(!SPIFFS.begin(true)){
        debugf("SPIFFS Mount Failed\n");
      }

      preferences.begin("led_pattern", false);
      debugf("Preffs free entries: %d\n", preferences.freeEntries());

      this->ledBrightness = preferences.getChar("brightness", 0x0A);
      debugf("- brightness = %d\n", this->ledBrightness);

      this->animationSpeed = preferences.getChar("animationSpeed", 0x0A);
      debugf("- animation speed = %d frames per sec\n", this->animationSpeed * 2);

      this->numberOfLeds = preferences.getChar("numberOfLeds", DEFAULT_NUMBER_OF_LEDS);
      debugf("- number of LEDs = %d\n", this->numberOfLeds);

      this->patternSlot = preferences.getChar("patternSlot", 0x00);
      debugf("- pattern slot = %d\n", this->patternSlot);

      this->patternBank = preferences.getChar("patternBank", 0x00);
      debugf("- pattern bank = %d\n", this->patternBank);

      loadFrameHeight();
      loadFrameCount();
      debugf("- frame\n");
      debugf("  - height = %d\n", this->frameHeight);
      debugf("  - count = %d\n", this->frameCount);
      
      fillDefaultPattern();

      loadPattern();

      debugf("- pattern\n");
      for (int i = 0; i < this->frameHeight * this->frameCount; i+=3 ) {
        if (i%this->frameHeight*3 == 0) {
          debugf_noprefix("\n");
          debugf("    ");
        }
        debugf_noprefix("0x%02X%02X%02X ", this->pattern[i], this->pattern[i+1], this->pattern[i+2]);
      }
      debugf_noprefix("\n");
      
      debugf("Setup complete\n");
    }

    void loop(){
      // Pattern Cycling
      if((this->displayState == DS_PATTERN_ALL || this->displayState == DS_PATTERN_ALL_ALL) && millis() - this->displayStateLastUpdated >  10000){
        this->setPatternSlot((this->patternSlot + 1) % PATTERN_BANK_SIZE, false);
        if(this->patternSlot == 0 && this->displayState == DS_PATTERN_ALL_ALL){
          this->setPatternBank((this->patternBank + 1) % PATTERN_BANK_COUNT, false);
        }
        this->displayStateLastUpdated = millis();
      }

      // Battery latching state
      if(batteryVoltage <= BATTERY_VOLTAGE_SHUTDOWN || batteryState == BAT_SHUTDOWN){
        batteryState = BAT_SHUTDOWN;
      }else if(batteryVoltage <= BATTERY_VOLTAGE_CRITICAL || (batteryState == BAT_CRITICAL && batteryVoltage <= BATTERY_VOLTAGE_CRITICAL + BATTERY_LATCH)){
        batteryState = BAT_CRITICAL;
      }else if(batteryVoltage <= BATTERY_VOLTAGE_LOW || (batteryState == BAT_LOW && batteryVoltage <= BATTERY_VOLTAGE_LOW + BATTERY_LATCH)){
        batteryState = BAT_LOW;
      }else {
        batteryState = BAT_OK;
      }
      
    }
};

#endif

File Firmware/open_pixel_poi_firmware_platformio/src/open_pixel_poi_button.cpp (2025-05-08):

#ifndef _OPEN_PIXEL_POI_BUTTON
#define _OPEN_PIXEL_POI_BUTTON

#include "open_pixel_poi_config.cpp"
#include <driver/rtc_io.h>
#include <driver/gpio.h>
#include "esp_sleep.h"

#define DEBUG  // Comment this line out to remove printf statements in released version
#ifdef DEBUG
#define debugf(...) Serial.print("<<button>> ");Serial.printf(__VA_ARGS__);
#define debugf_noprefix(...) Serial.printf(__VA_ARGS__);
#else
#define debugf(...)
#define debugf_noprefix(...)
#endif

enum ButtonState {
  BS_INITIAL,
  BS_CLICK_DOWN,
  BS_CLICK_HOLD,
  BS_CLICK_HOLD_LONG,
  BS_CLICK_UP,
  BS_CLICK2_DOWN,
  BS_CLICK2_HOLD,
  BS_CLICK2_UP,
  BS_CLICK3_DOWN,
  BS_CLICK3_HOLD,
  BS_CLICK3_UP,
  BS_CLICK4_DOWN,
  BS_CLICK4_HOLD,
  BS_CLICK4_UP,
  BS_CLICK5_DOWN,
  BS_CLICK5_HOLD,
  BS_CLICK5_UP
};

class OpenPixelPoiButton {

private:
  OpenPixelPoiConfig& config;

  int filteredButtonInput = 1000;
  int buttonState = 0;
  long downTime = 0;
  bool regulatorEnabled = true;

  long shutDownAt = 0;

public:
  OpenPixelPoiButton(OpenPixelPoiConfig& _config): config(_config) {}    

  void setup() {
    // Voltage Input
    pinMode(A0, INPUT);

    //Button Input
    pinMode(3,INPUT_PULLUP);

    // Regulator Output
    pinMode(D7, OUTPUT);
    regulatorEnabled = true;
    digitalWrite(D7, HIGH);

  }

  void loop() {
    filteredButtonInput = (filteredButtonInput * 0.92) + (analogRead(3) * .08);
    if(filteredButtonInput < 100){
      if(buttonState == BS_INITIAL){ // Single Click
        downTime = millis();
        buttonState = BS_CLICK_DOWN;
        // Trigger Waiting Animation
        config.displayState = DS_WAITING;
        config.displayStateLastUpdated = millis();
      }else if(buttonState == BS_CLICK_UP){ // Double Click
        downTime = millis();
        buttonState = BS_CLICK2_DOWN;
        // Trigger Waiting Animation
        config.displayState = DS_WAITING2;
        config.displayStateLastUpdated = millis();
      }else if(buttonState == BS_CLICK2_UP){ // Triple Click
        downTime = millis();
        buttonState = BS_CLICK3_DOWN;
        // Trigger Waiting Animation
        config.displayState = DS_WAITING3;
        config.displayStateLastUpdated = millis();
      }else if(buttonState == BS_CLICK3_UP){ // Quad Click
        downTime = millis();
        buttonState = BS_CLICK4_DOWN;
        // Trigger Waiting Animation
        config.displayState = DS_WAITING4;
        config.displayStateLastUpdated = millis();
      }else if(buttonState == BS_CLICK4_UP){ // Penta Click
        downTime = millis();
        buttonState = BS_CLICK5_DOWN;
        // Trigger Waiting Animation
        config.displayState = DS_WAITING5;
        config.displayStateLastUpdated = millis();
      }else if(buttonState == BS_CLICK_DOWN && millis() - downTime >= 500){ // Click Hold
        buttonState = BS_CLICK_HOLD;
        // Trigger voltage display
        config.displayState = DS_VOLTAGE;
        config.displayStateLastUpdated = millis();
      }else if(buttonState == BS_CLICK_HOLD && millis() - downTime >= 3000){ // Click Long Hold
        buttonState = BS_CLICK_HOLD_LONG;
        config.displayState = DS_SHUTDOWN;
        config.displayStateLastUpdated = millis();
        shutDownAt = millis();
      }else if(buttonState == BS_CLICK2_DOWN && millis() - downTime >= 500){ // Click2 Hold
        buttonState = BS_CLICK2_HOLD;
        // Trigger bank display
        config.displayState = DS_BANK;
        config.displayStateLastUpdated = millis();
      }else if(buttonState == BS_CLICK3_DOWN && millis() - downTime >= 500){ // Click3 Hold
        buttonState = BS_CLICK3_HOLD;
        // Trigger voltage display
        config.displayState = DS_BRIGHTNESS;
        config.displayStateLastUpdated = millis();
      }else if(buttonState == BS_CLICK4_DOWN && millis() - downTime >= 500){ // Click4 Hold
        buttonState = BS_CLICK4_HOLD;
        // Trigger speed display
        config.displayState = DS_SPEED;
        config.displayStateLastUpdated = millis();
      }else if(buttonState == BS_CLICK5_DOWN && millis() - downTime >= 500){ // Click5 Hold
        buttonState = BS_CLICK5_HOLD;
        // Do Nothing (display pattern)
        config.displayState = DS_PATTERN;
        config.displayStateLastUpdated = millis();
      }
    }else{
      if(buttonState == BS_CLICK_DOWN){
        buttonState = BS_CLICK_UP;
      }else if(buttonState == BS_CLICK2_DOWN){
        buttonState = BS_CLICK2_UP;
      }else if(buttonState == BS_CLICK3_DOWN){
        buttonState = BS_CLICK3_UP;
      }else if(buttonState == BS_CLICK4_DOWN){
        buttonState = BS_CLICK4_UP;
      }else if(buttonState == BS_CLICK5_DOWN){
        buttonState = BS_CLICK5_UP;
      }else if(buttonState == BS_CLICK_HOLD){
        buttonState = BS_INITIAL;
        config.displayState = DS_PATTERN;
        config.displayStateLastUpdated = millis();
      }else if(buttonState == BS_CLICK2_HOLD){
        if(millis() - downTime < 1000){
          config.setPatternBank(0, true);
          config.displayState = DS_PATTERN;
          config.displayStateLastUpdated = millis();
        }else if(millis() - downTime < 1500){
          config.setPatternBank(1, true);
          config.displayState = DS_PATTERN;
          config.displayStateLastUpdated = millis();
        }else if(millis() - downTime < 2000){
          config.setPatternBank(2, true);
          config.displayState = DS_PATTERN;
          config.displayStateLastUpdated = millis();
        }else{
          config.displayState = DS_PATTERN_ALL_ALL;
          config.displayStateLastUpdated = millis();
        }
        buttonState = BS_INITIAL;
      }else if(buttonState == BS_CLICK3_HOLD){
        if(millis() - downTime < 1000){
          config.setLedBrightness(1);
        }else if(millis() - downTime < 1500){
          config.setLedBrightness(4);
        }else if(millis() - downTime < 2000){
          config.setLedBrightness(10);
        }else if(millis() - downTime < 2500){
          config.setLedBrightness(25);
        }else{
          config.setLedBrightness(100);
        }
        buttonState = BS_INITIAL;
        config.displayState = DS_PATTERN;
        config.displayStateLastUpdated = millis();
      }else if(buttonState == BS_CLICK4_HOLD){
        if(millis() - downTime < 1000){
          config.setAnimationSpeed(0);
        }else if(millis() - downTime < 1500){
          config.setAnimationSpeed(1);
        }else if(millis() - downTime < 2000){
          config.setAnimationSpeed(2);
        }else if(millis() - downTime < 2500){
          config.setAnimationSpeed(5);
        }else if(millis() - downTime < 3000){
          config.setAnimationSpeed(10);
        }else if(millis() - downTime < 3500){
          config.setAnimationSpeed(20);
        }else if(millis() - downTime < 4000){
          config.setAnimationSpeed(50);
        }else if(millis() - downTime < 4500){
          config.setAnimationSpeed(100);
        }else if(millis() - downTime < 5000){
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

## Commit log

2023-05-11 add Firmware/led_remixer_firmware
2023-05-13 fix some buffer and data type issues; rename to open_pixel_poi
    [led_remixer_firmware.ino, open_pixel_poi_config.cpp]
2023-05-30 Migrate to v2 pinout, add sleep, voltage, brightness, and speed controls via button
2023-05-30 Add 3d model
    [OpenPixelPoiAllParts.3mf]
2023-05-30 Update OpenPixelPoiAllParts.3mf
    Fixed battery sheath missing slots
    [OpenPixelPoiAllParts.3mf]
2023-05-31 Realtime rendering, Better Speed control, tweak battery display, add switch info
2023-06-09 Switch to flutter blue plus, fix reconnections
2023-06-10 Set pattern slot, better speed adjustment
2023-06-10 Add wiring diagram
    [wiring.fzz]
2023-06-22 Firmware updates
    Add pattern cycle mode with ble command, voltage display mode, low battery warnings, remove loop delay, prevent lockup on multipart ble timeout, improve shutdown, refactor button code, increase filter on button and voltage, disable serial debug stuff, probably more things too
    [open_pixel_poi_button.cpp, open_pixel_poi_config.cpp]
2023-06-23 App updates Block ui while uploading patterns Upload to each poi sequentially Cache images in memory Update default patterns Clean up db code a lil Add support for demo mode Change sliders into butto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
2023-07-01 Fix framerate aliasing issues
2024-08-29 test board save state
    designed a breakout board, saving state so i can reference back to it if i ever need to, as i have a stack of them sitting around.
    [ESP32-C3-MINI-1-N4.step, bom.csv, designators.csv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]
2024-11-24 Start on new PCB
    [kicad.kicad_pcb, kicad.kicad_sch]
2025-03-05 Hardware Updates
    [bom.csv, designators.csv, kicad.kicad_pcb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]
2025-03-23 Hardware 2.2.1
    [bom.csv, designators.csv, positions.csv]
2025-03-23 Better low voltage handling
2025-03-25 Migrate mobile app to 2025 packages and ide
    [kicad.kicad_sch]
2025-03-30 Add merge pattern creator and other tweaks
    [kicad.kicad_pcb]
2025-03-31 Fix scan button
2025-04-01 Documentation updates
    [OpenPixelPoiAllParts.3mf, bom.csv, designators.csv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]
2025-04-01 Update assembly guide
    [wiring.fzz]
2025-04-05 PCB Tweaks
    [kicad.kicad_pcb, kicad.kicad_sch]
2025-04-10 Few pcb tweaks
2025-05-02 3D Files update
    [Open Pixel Poi - All Parts In One File.3mf, Open Pixel Poi - Body - Bottom.3mf, Open Pixel Poi - Body - Button.3mf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]
2025-07-28 working button with 1A module
2025-11-08 battery voltage adjust pixel fix
2026-09-06 Add KiCad MCP configuration and new script for editing schematic text
    - Introduced a new MCP configuration file for KiCad.
    - Added a Python script to automate the editing of schematic text, including functionality for managing component instances and labels.
    - Updated the platformio.ini to streamline the default environment settings.
    - Adjusted firmware BLE handling for pattern saving and button state management.
    - Modified LED handling to support multiple strips and improved brightness control.
    - Updated KiCad PCB files and removed obsolete autosave files.
2026-10-16 Fix ESP32-C3 build: use GPIO wakeup for button deep sleep
    ext0 wakeup is not available on the ESP32-C3, so the 80px firmware only
    built for the S3. On the C3, wake on LOW on the button pin (A1 = GPIO3)
    via esp_deep_sleep_enable_gpio_wakeup. S3 path is unchanged.
    Tested on XIAO ESP32-C3 + staff PCB v6: boots, button and LED1 (D8) work.
